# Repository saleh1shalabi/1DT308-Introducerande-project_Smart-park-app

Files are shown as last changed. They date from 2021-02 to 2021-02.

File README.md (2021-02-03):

# team-18

# Smart car counter

## Abstract

Cant see embedded video? Here is the link!
https://youtu.be/MCtellI5bu4

This project aims to provide an better alternate method of keeping track of parking spaces in a parking lot. The current setup is stationary and prone to faults, thus the soulution should be a reliable and portable one. 

A portable device to be placed on each driving lane was developed, making use of a motion detector sensor. The sensor is triggered when a car passes over it and data is sent to an app that presents the live number of available parking spaces. 

## Background and idea
Kalmar kommun asked students at Linneaus university to: Parkeringsplats, fullt eller inte fullt, antal lediga platser. There is a solution right now doing this at many parkingspaces around the city, however there are problems with the current solution. It often show the wrong number of available spaces, and after talking to the contact person at Kalmar kommun, we understand that it requires a subscription or sorts.

Our first idea was to make a stationary solution, but after talkking to the contact at Kalmar kommun, and to our teacher it became clear that a portable sulotion would be more in line with what Kalmar kommun had in mind, and more in scope with the assignment. 

The initial idea was to have two sensors at a distance from eachother, and assume that the one that the car passes first would trigger first. This assumption would then be used to determine the direction of the car. The sensor that was chosen turned out to detect movement in all directions, making it very likely to detect things that are not cars. Taking this in to consideration it was decided that we would instead make a device that is to be placed on the drivinglane so that the cars drive over it. The fact that it now is blocked from below, and is furher from where people are likely to walk will hopefully help with only detecting cars. 

To further help with this the sensor could be shielded on the sides, a resistor can also be added that shortens the sensors range and thus reduce the likelihood of detecting people, birds ect.

Whith the cars driving over the detector, a lazer distance sensor cound probably be used, we didn't consider them with our other ideas because of their typically short range. On the other hand, utilising such a sensor, you could probably be very sure that it only triggers when a car drives over it.

We tried to power it with a 9V battery conected to the sensor, and then power the lopy4 via the sensors 3V3.

To determine the direction of the cars one device is placed on each driving-lane. There is a button on the device that lets you switch between the device laying on a lane where cars drive in to, or out of the parkinglot. Data is then, when the sensor is triggerd, sent to a calculator and middlehand to determine the number of available parking spaces. 

## Method

[Timelog](doc/timelog.md)

[Requirements](doc/requirements.md)

[Hardware](doc/hardware.md)

[Setup](doc/setup.md)

[Test](doc/test.md)

## Results

We succeded with making a program that works as intended with the buttons and the LEDs and the sensor. There is also a 3D printed case for everything and there was an atempt to solder everything together and have it work as a portable unit. we got it to work a few times u it did not work well and was super flimsy. The explanation was probably that we did not have a good solution for powering the device. The lopy4 turned out to need 3.5-5 V in and thus the 3v3 output was to weak. When trying to fix this useing a voltage regulator something went wrong and the lopy4 burned out (sorry) So now our only currently working option is to use a powerbank with USB.

We have a working app that that can display the data, it is also possible to change a few settings such as location as well as reading a little about the product and the members of the team.

Sending and reciving data via LORA and MQTT is still not working as well as we would want and this causes the data in the app and the data sent by the sensor to not agree 100 %.

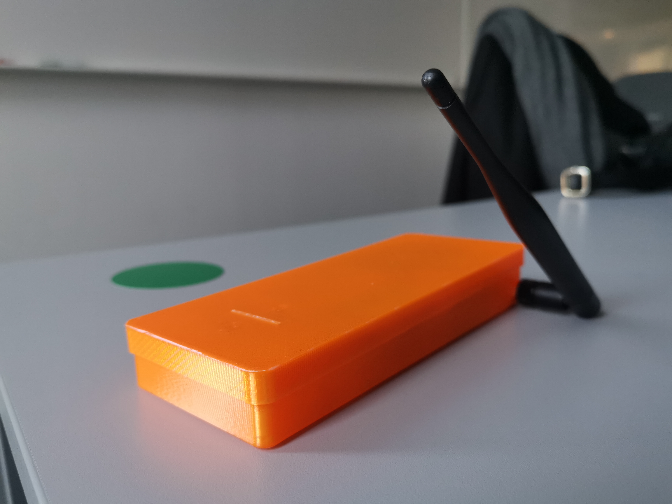
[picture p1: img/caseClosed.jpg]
case

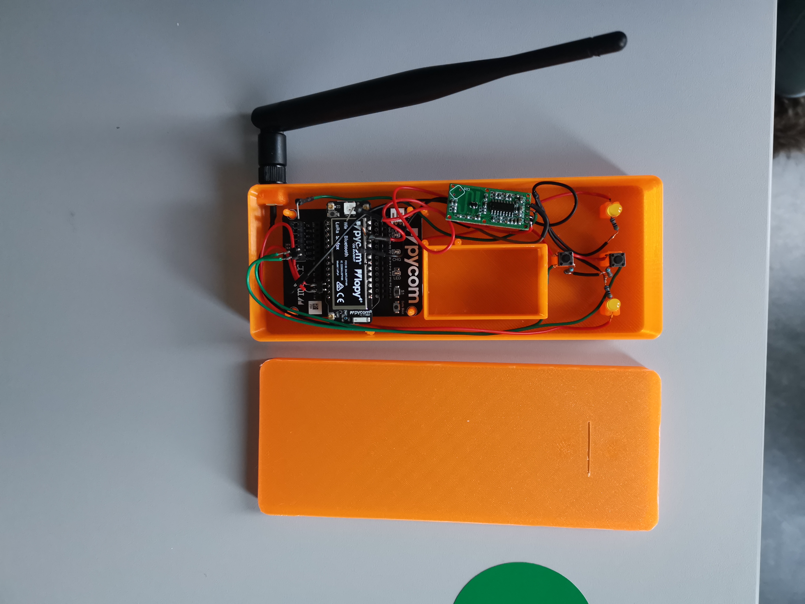
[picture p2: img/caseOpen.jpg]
case inside


## Reflections

### Emelie

Min uppgift var att ta hand om uppkopplingen. Det började med en tanke om att använda TTN för att sedan skicka vidare datan till en MQTT server genom en IFTTT applet. Detta skrotades till sist och ersattes av LoPy to LoPy kommunikation och direkt kommunikation till MQTT-servern via wifi.

Det svåraste med projektet var att komma igång. Vi hängde upp oss på sensorn mer än vi skulle gjort vilket satte stopp för resten av arbetet. Att man är ovan vid grupparbete på distans gjorde inte saken bättre.

Det roligaste var att få hålla på och koppla och testa sig fram för att få sensorn funka (så gott den kunde).

### Saleh

Detta var första gången för mig att programera en app. Det var väldigt utmanande att kunna presentera datan på ett snyggt sätt som det jag kom fram till med i appen, tycker jag åtminstone. Väldigt kul och lärorikt upplevelse.  Eftersom appen behöver få in datan var det lämpligast att programera huvudenheten samtidigt. 

Svårast var det att kunna lära sig flera olika bibliotek på så kort tid. Vissa gånger ville scripten bara inte fungera trötts att det inte fanns något fel i det. Väldigt utmanande att hitta på flera olika sätt att kunna lösa en och samma sak, bara för att ibland ville det inte fungera som man ville.

Jag är väldigt nöjd över det jag fick lära mig under detta projekt, att man fick välja precis det man ville göra var nog det bästa med det då det är mest lärande att man gör något man tycker om! :)

### Elin

Jag var mest ansvarig för vilken logik som skulle användas när sensorn detekterade någonting, att koppla ihop och programmera hårdvaran och att designa ett case till alla delar.

Det svåraste var att släppa att sensorn inte var optimal för ändamålet och den lösning vi hade tänkt först, tillslut blev det någon sorts kompromiss där vi körde på den befintliga sensorn, men försökte anpassa lösningen till hur den funkar.

Det roligaste var att koppla ihop allting och se hur det fungerade tillsammans. Det var kul att lära sig mer om att arbeta i 3D, och det var kul att löda ihop allting, även om något gick fel så att det inte funkade på slutet.

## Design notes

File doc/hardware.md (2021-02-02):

# Hardware and hardware setup 

* LoPy 4
* Antenna
* RCWL-5016
* 9 V powersource
* 2 Leds
* 2 buttons
* 2 1K ohm pulldownresistor

## Explanations

The two leds will be used to indicate if the device is meant to be placed on the in-lane or on the out-lane. The device is placed in the middle of the drivinglane, its range is hopefully short enough so that something detected can be assumed to be a car driving on the in-lane --> +1 car on the parkinglot. One of the buttons is to swich between these two modes. The other button is to start and stop the process of detecting cars and sending data.The sensor has a 360 degree detection range radar that sends out microwaves and measures potential differenses in the returning wavelengths to determine movement. 

## Setup

koppligsschema

Each component is connected with cables here represented by "<-->".

#### OUT-LED
* LoPy4 P12 <--> LED <--> resistor <--> LoPy4 GND

#### IN-LED
* LoPy4 P11 <--> LED <--> resistor <--> LoPy4 GND

#### Start/stop button
* LoPy4 P9 <--> Button <--> resistor <--> LoPy4 GND
* Button <--> LoPy4 3V3

#### Button switch
* LoPy4 P8 <--> Button <--> resistor <--> LoPy4 GND
* Button <--> LoPy4 3V3

#### RCWL-5016
* LoPy4 VIN(can be used as 5V powersource) <--> RCWL-5016 VIN
* RCWL-5016 output <--> LoPy4 P6
* RCWL-5016 GND <--> LoPy4 GND

#### Antenna
* Directly connected to either of LoPy4's LoRa antennas.

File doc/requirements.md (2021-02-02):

# Car counter

## Problem
Kalmar kommun has specified the following problem: Parkeringsplats, fullt eller inte fullt, antal lediga platser.

* People park for to long or without paying.
* The current way to count available parkingspaces does not work well.

___
## User stories
* *US1*: As a user I must be able to access information about how many cars has entered and exited the parkinglot since the device was placed.
* *US2*: As a user I could be able to enter the number of cars that are already on the parkinglot.
* *US3*: As a user I could be able to enter the total number of parkingspaces on the parkinglot.
* *US4*: As a user I could be able to see how many free spaces there are on a certain parkinglot.
___
## Device requierments

* *DR1*: The device must be portable and easy to set up.
* *DR2*: The device must be a selfcontained unit.
* *DR3*: The device must try to utilize the available sensors.
* *DR4*: The device must be safe to place.
* *DR5*: The device could use a magnetic sensor to further verify that is is a car and not something else.
---
## Breakdowns

### **User story breakdowns**

* **US1**
    * US11: When the device detects a car this information is saved and sent to a server.
    * US12: By subscribing to this server you can access the information about the number of cars that have entered or exited the parkinglot.

* **US2**
    * US21: The case of the device have buttons that make it possible to enter numbers.
    * US22: The case of the device has a little screen that ask the user to enter the number of cars. 
    * US23: The screen can show what number have been entered.
    * US24: The case of the device have an 'OK' or 'Enter' button wich the user can press to finish writing in the number.
    * US25: The entered number is sent to the server.

* **US3**
    * US31: See US21
    * US32: See US22
    * US33: See US23
    * US34: See US24
    * US35: See US25

* **US4**
    * US41: When the server recives in formation about the number of spaces it subtracts used spaces from total spaces.
    * US42: Each time a car exits or enters the available space change.

### **Device requirement breakdowns**

* **DR1**
    * DR11: The device must be relativley easy to move and carry.
    * DR12: A user should be able to carry the device in one hand.
    * Placing the device should be as simple as laying it on the ground or atatching it to a dedicated mount.

* **DR2**
    * DR21: A case should be designed that contains everything the device needs.
        * lopy 4
        * battery
        * Lora antenna
        * Sensors 
        * screen (if time permitts)
        * Buttons (if time permitts)
        * coil (if time permitts)
    
    * DR22: The case is designed to be 3D-printed.

* **DR3**
    * DR31: Different ways of utilising the RCWL-0516.
        * One device for each lane
        * Each time the sensor gives a signal it is counted as a car.
        * The direction of the car is determined based on wich lane the device is placed on.
    * DR32: Problems with the RCWL-0516.
        * The sensor 'looks' in all directions, so it will detect cars in other places than the lane it is placed on.
        * The sensor reacts to pedestrians.
        * The sensor seams unreliable. 
    * DR33: The sensor could be screened of to help with some of the problems.

    * DR34: Designing the device to be placed on the lane with the sensor facing uppwards could help with some of the problems.
        * Cars drive over the cevice.
        * Device must be flat and low to the ground.
        * Device must be highley vissible.
    * Adding the resistor that limits the sensors range from 7 meters to 5 meters could help with some of the problems.

* **DR4**
    * DR41: Placing the device must not involve spending unnescesery time on or in conection to the road.
    * DR42: While placing the device the user must be able to be highly vissible.
    * DR43: While placing the device the user must be able to keep their attention on their suroundings. 

* **DR5**
    * DR51: Different magnetic sensors that could be used:
        * digital hall sensor.
        * A coil (placed iside, around the edges of a round case)
    * DR52: When the RCWL-0516 sences something the magnetic sensor verifies that it is likely a car and not a pedestrian.

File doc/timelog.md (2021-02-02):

# Timelog

|Date | Activity | Time
|:-:|:-|:-:|
| 2/12 | Alla träffades för att planera parkering mm. | 45-60 min |
| 3/12 | Alla hade möte med Simon Vestlund ang projektet. | 20 min |
|| Gruppmedlemmarna hade samtal efter mötet | 15 min |
| 8/12 | Emelie jobbade med conencting. | 2h |
|| Saleh arbetade med lora, förståelse om pycom kontakten enhet till enhet via lora, kollade alt. om en Mqtt broker/server skulle skapas på egen hand. | 3h |
| 10/12 | Alla har möte med Fredrik.| 20 min |
|| Alla hade ett litet möte | 20 min |
|| Alla försöker bestämma sig för sensortyp mm. |  5h  |
|| Saleh läste om webserverar | 2h |
|| Saleh fortsatte kolla med appen | 1h |
| 11/12 | Saleh kollade hur man skapar en mobil app, läste om kivy och kivymd, kollade buldozer som pressar program filerna till mobil app. | 6h|
| 16/12 | Alla experimenterar med sensor och pratar i Discord | 5h |
|| Saleh fortsatte kolla med appen | 1h|
| 17/12 | Emelie och Saleh möte med Fredrik. | 15 min |
|| Alla samtal | 30 min |
|| Emelie jobbade med connection. | 2h |
|| Saleh test skapa enkla appar för att ha djupare förståelse till det | 5h |
| 18/12 | Emelie fixade IDE/pymakr som gett upp. | 3h |
|| Saleh mer om mobilappar och kollade sensorn med test köra lite kod med den för att få den att funka. | 3h |
| 4/1 | Alla hade planeringsmöte. | 3h |
|| Saleh kollade alt sensor | 1.5h |
| 6/1 | Emelie försökte få uppkoppling att funka.| 3h |
| 7/1 | Elin börjar skriva kravspec | 1 tim |
|| Emelie fortsatte med uppkoppling och även gateway. | 2h|
||  Alla hade möte om hur vi ska gå tillväga. | 2h |
| 8/1 | Emelie löste uppkoppling (äntligen). | 3h |
| 9/1 | Emelie kopplade TTN till io.adafruit.| 40min |
| 10/1 | Elin skriver requirement breakdowns | 2.5h |
||  Saleh app designen, kollade med ttn kopplingen och lora | 4h |
|| Elin gör det möjligt att välja vilket läge enheten är i | 3 tim |
|| Alla har samtal | 30 min |
|11/1| Elin jobbar med prototyp. lägger till startknapp och sensor | 4 tim |
|| Elin ritar kopplingsschema för prototyp | 30 min |
||Elin jobbar med delivarables | 2 tim |
|| Saleh Jobbar med mqtt uppkoppling och appen | 5h |
|12/1| Elin designar case | 8 tim |
|13/1| Elin kopplar och löder ihop allting för att passa i caset|5 tim|
|14/1| Alla jobbade med det sista med conenction och hardware | 8h |
|| Alla hade möte | 2h |
|| Saleh fixade med appen | 5h |
|15/1| Alla jobbar med finslip, hardware-strul och film | 10h |

## Diagram

Blue - Saleh
Red - Emelie
Yellow - Elin
Green - All

case

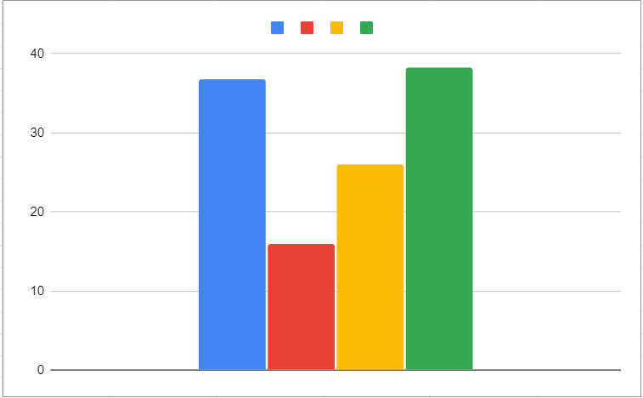
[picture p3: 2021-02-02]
img/time.PNG

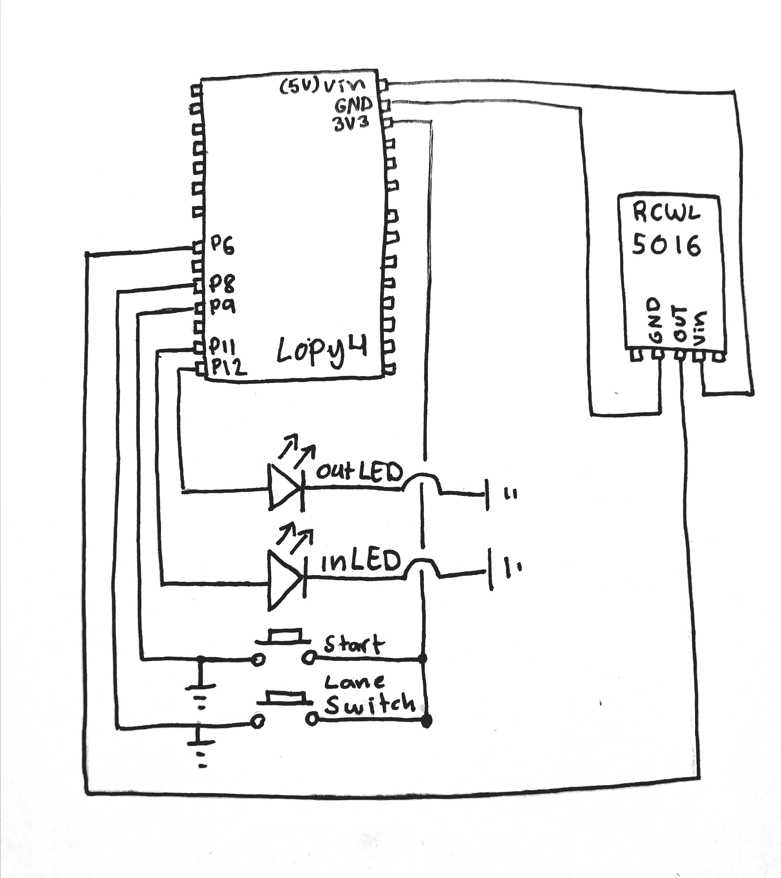
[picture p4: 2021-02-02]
img/Kopplingsschema.jpg

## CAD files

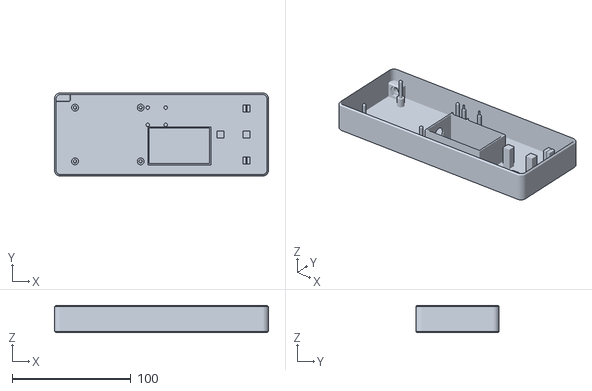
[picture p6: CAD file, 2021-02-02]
img/case/case.stl
180.0 x 70.0 x 23.0

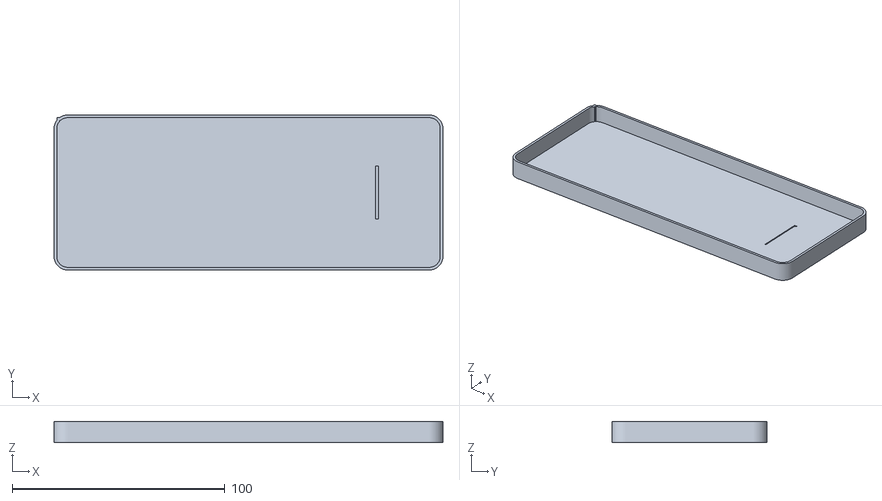
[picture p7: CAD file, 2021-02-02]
img/case/lid.stl
183.0 x 73.0 x 10.0

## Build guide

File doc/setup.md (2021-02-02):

# Setup

## Components

* io.adafruit
    * feed - recieves data from main_device_code
* car_counter
    * main.py - buttons and LED's controlls, sends message to main device when sensor is triggerd, either Car_IN or Car_OUT
    * boot.py - connect to lora
* main_device_code
    * main.py - recives data from car_counter, uploads data to MQTT server, calculates the net sum of passing cars, conencts to lora, wifi and MQTT
    * boot.py - 
    * lib -  
* app
    * main.py - create the graphical interface the presents the collected data
    * connect.py - connects to MQTT

## Setup

### io.adafruit

The only setup needed is to change the authentications for the MQTT server and wifi. 

### car_counter

You might need to change the pin numbers to correspond with the pins you chose when setting up your hardware. If bouncing is going crazy you could try to adjust the variable "bounceTime". You can also adjust how the LEDs behave. Look for this part in the code: 

```{python}

#----------------------------------------------------------------------
#Variables you might want to adjust

bounceTime = 100 # how much time must pass when checking for button bounce

#LIGHTS
blinkRepeat = 3 # how many times the lights will blink when the device starts or stops counting cars.
blinkTimeON = 0.2 # how long time the lights will be on when blinking
blinkTimeOFF = 0.5 # how long the lights will be off when blinking
timeON = 1 # how long the light will be on when indicating a switch
#-------------------------------------------------------------------------
```

### main_device_code

Authentications for wifi connection will need to be changed to the proper one.

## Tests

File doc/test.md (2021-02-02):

# Test

Take a lopy device and run the car_counter code. Press the 'switch' button: one of the LEDs should light up for a second to indicate witch mode is chosen, when the button is pressed again the other LED should light up. Press the buttons a few times and look at the terminal to see if there is bouncing. if the led changes again directly after a press the softwhere didnt succesfully identify a bounde. choose one LED. Press the start button, the chosen LED should blink three times. Set up a MQTT server with a feed to subscribe to. Now take another lopy and run the "main_device_code" code and alter authentication as needed, the MQTT should display a number that alter when the sensor is triggerd. Either adding or subtracting depending on the chosen LED. Test for both LED's. Look in the terminal of car_counter and see if it prints 'car going in' and 'car going out accordinly'.

When you run the main_device_code you can look in the terminal at the messages it is recieving. When the 'in-lane-mode' is chosen the message should be 'Car_IN', when the out-lane LED is chosen the message should be 'Car_OUT'. If you want to check witch mode is the current one, press the start button again and the LED corresponding to the current mode should blink three times. A message is sent each time the sensor detects movement. If you press the switch button the other led should blink three times and the message should change. When you want to stop sending messages and lisstening to the sensor hold the start button for about 10 seconds when both lights light up it means the car counting has stopped. if one LED blinks when you press the button, or after both leds lit up it is because of bouncing. Try holding the button again.

Tip!
If you want to have more control of when a message is sent, for testing, you could change the sensor for another button. Connect in the same manner as the other buttons.

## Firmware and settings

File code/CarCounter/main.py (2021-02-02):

from machine import Pin
import time
import utime
import _thread
import socket
import struct
import pycom

#boolians to let me check what is going on at a given moment.
inLane = True
justStopped=False
blinking = False

s = socket.socket(socket.AF_LORA, socket.SOCK_RAW)
s.setblocking(False)

#timestamps to check bouncing. Tame for car is needed when testing with a button
#instead of a sensor.
timeForLastSwitch = utime.ticks_ms()
timeForStartButton = utime.ticks_ms()
timeForCar = utime.ticks_ms()

inLaneLed = Pin('P11', mode=Pin.OUT)
outLaneLed = Pin('P12', mode=Pin.OUT)

startButton = Pin('P9',mode=Pin.IN, pull=None)
laneSwitchButton = Pin('P8', mode= Pin.IN, pull=None)
motionSensor = Pin('P6', mode=Pin.IN)
#----------------------------------------------------------------------
#Variables you might want to adjust

bounceTime = 100 # how much time must pass when checking for button bounce

#LIGHTS
blinkRepeat = 3 # how many times the lights will blink when the device starts or stops counting cars.
blinkTimeON = 0.2 # how long time the lights will be on when blinking
blinkTimeOFF = 0.5 # how long the lights will be off when blinking
timeON = 1 # how long the light will be on when indicating a switch

#-------------------------------------------------------------------------

print('starting')

#this function is called when the 'switch' button is pressed.
def laneSwitch(argument):

    global inLane
    global timeForLastSwitch
    global inLaneLed
    global outLaneLed
    global timeON


    if bounceCheck(timeForLastSwitch):
        return

    if inLane:
        inLaneLed.value(0)
        outLaneLed.value(1)
        print('I just swiched from in lane to out lane!')

    else:
        inLaneLed.value(1)
        outLaneLed.value(0)
        print('I just swiched from out lane to in lane!')
    time.sleep(timeON)
    inLaneLed.value(0)
    outLaneLed.value(0)
    inLane = not inLane
    timeForLastSwitch = utime.ticks_ms()

def startFunction(argument):

    global startButton
    global timeForStartButton
    global justStopped

    if bounceCheck(timeForStartButton):
        return

    timeForStartButton = utime.ticks_ms()

    #we will stop by holding in the start button. when we let it go, this will
    #trigger a new startFunction, unless we make it so we can check if we just
    #stopped.
    if justStopped:
        justStopped = False
        return

    startButton.callback(Pin.IRQ_FALLING, None)

    print('starting')
    _thread.start_new_thread(mainCarCountingFunction, ())
    _thread.start_new_thread(blinkLightsXTimes, ())


def stopFunction(argument):

    global startButton
    global timeForStartButton
    global motionSensor
    global justStopped
    #
    # if time.ticks_diff(utime.ticks_ms(), timeForStartButton) < 100:
    #     print('to soon probably a bounce')
    #     return
    print('stopFunction')
    timeForStartButton = utime.ticks_ms()

    #will stop the car counting if start button is held for five seconds.
    while startButton.value() == 1:

        if utime.ticks_diff(utime.ticks_ms(), timeForStartButton) > 5000:
            print('no more car')
            motionSensor.callback(Pin.IRQ_RISING, None)
            timeForStartButton = utime.ticks_ms()
            bothLights()
            startButton.callback(Pin.IRQ_FALLING, startFunction)
            justStopped=True

            return
    blinkLightsXTimes()



def mainCarCountingFunction():
    global motionSensor
    global startButton
    global timeForStartButton

    time.sleep(3)
    print('entering a loop')
    motionSensor.callback(Pin.IRQ_RISING, carDetected)
    startButton.callback(Pin.IRQ_RISING, stopFunction)


def carDetected(argument):
    global timeForCar

    #needed when using a button while testing
    if bounceCheck(timeForCar):
        return

    timeForCar = utime.ticks_ms()

    if inLane:
        print('Car detected going in')
        s.send('Car_IN')
    else:
        print('Car detected going out')
        s.send('Car_OUT')

#blinks light ineffinetley, battery draining
def blinkLights():
    global blinking
    global outLaneLed
    global inLaneLed

    blinking = True
    while blinking:
        if inLane:
            blinkThisLight(inLaneLed)
        else:
            blinkThisLight(outLaneLed)

def blinkLightsXTimes():
        global blinkRepeat
        global outLaneLed
        global inLaneLed


        for _ in range(blinkRepeat):
            if inLane:
                blinkThisLight(inLaneLed)
            else:
                blinkThisLight(outLaneLed)


def blinkThisLight(light):

        global blinkTimeON
        global blinkTimeOFF

        light.value(1)
        time.sleep(blinkTimeON)
        light.value(0)
        time.sleep(blinkTimeOFF)

def stopBlinking():
    global blinking
    blinking = False

def bothLights():
    global inLaneLed
    global outLaneLed
    global timeON

    inLaneLed.value(1)
    outLaneLed.value(1)
    time.sleep(timeON)
    inLaneLed.value(0)
    outLaneLed.value(0)

def bounceCheck(timeStamp):

    global bounceTime

    if time.ticks_diff(utime.ticks_ms(), timeForLastSwitch) < bounceTime:
        print('to soon probably a bounce')
        return True
    return False


print('after functions')


laneSwitchButton.callback(Pin.IRQ_FALLING, laneSwitch)
startButton.callback(Pin.IRQ_FALLING, startFunction)

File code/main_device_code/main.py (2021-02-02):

import machine
import pycom
from network import LoRa
from network import WLAN
import socket
import time

from mqtt import MQTTClient


# lora to lora connect
lora = LoRa(mode=LoRa.LORA, region=LoRa.EU868)

s = socket.socket(socket.AF_LORA, socket.SOCK_RAW)
s.setblocking(False)

time.sleep(2)




Cars_TOT = 0            # parked cars defult value
Places = 50             # availble places defult value
car_count = 0           # checker




wlan = WLAN(mode=WLAN.STA)

def wifi_connect():
    # connect to wifi
    wlan = WLAN(mode=WLAN.STA)
    wlan.connect("LNU-iot", auth=(WLAN.WPA2, "modermodemet"), timeout=5000)

    while not wlan.isconnected():
        machine.idle()
    print("Connected to WiFi\n")



wifi_connect()




def sub_cb(topic, msg):
    global Cars_TOT, Places, car_count

    if msg == b"update": # when msg "update" publish values
        client.publish(topic="saleh_shalabi/feeds/Cars_TOT", msg=str(Cars_TOT))
        client.publish(topic="saleh_shalabi/feeds/Places", msg=str(Places))
    if topic == b"saleh_shalabi/feeds/reset_Cars":  # when msg gotten on reset car topic changes the values
        Cars_TOT = int(msg.decode("utf-8"))
        car_count = Cars_TOT

    if topic == b"saleh_shalabi/feeds/reset_Plac": # when msg gotten on reset places values
        Places = int(msg.decode("utf-8"))

    return Cars_TOT, Places, car_count







client = MQTTClient("lopy-saleh", "io.adafruit.com",user="saleh_shalabi", password="aio_eTQR01nk0h3dknsfy28Y37iWfW7c", port=1883)


client.set_callback(sub_cb)

client.connect()
client.subscribe(topic="saleh_shalabi/feeds/App")
client.subscribe(topic="saleh_shalabi/feeds/reset_Plac")
client.subscribe(topic="saleh_shalabi/feeds/reset_Cars")



print("mqtt connected")

while True:
    try:
        while not wlan.isconnected(): # if connection lost
            wifi_connect() # reconnect to wifi
            # re connect to mqtt server

            client.connect()
            client.subscribe(topic="saleh_shalabi/feeds/App")
            client.subscribe(topic="saleh_shalabi/feeds/reset_Plac")
            client.subscribe(topic="saleh_shalabi/feeds/reset_Cars")
            print("Conncetion lost, but istablished agane")
        else:
            client.check_msg() # check msg on mqtt


            if s.recv(64) == b'Car_IN':  # if a msg by lora from a device and its "Car_IN"
                print(s.recv(64))
                if Places == 0:         # check the values
                    print("where Are u going to park")
                else:                   # new values if there is places
                    Cars_TOT = Cars_TOT + 1
                    Places = Places - 1

            if s.recv(64) == b'Car_OUT':    #   if a msg by lora from a device and its "Car_OUT"
                print(s.recv(64))
                if Cars_TOT == 0:               # check values
                    print("how did this car even got in")
                else:                               # new values
                    Cars_TOT = Cars_TOT - 1
                    Places = Places + 1

            # check new values and publish it
            if Cars_TOT == (car_count +1):
                print("Cars + 1")
                client.publish(topic="saleh_shalabi/feeds/Cars_TOT", msg=str(Cars_TOT))
                client.publish(topic="saleh_shalabi/feeds/Places", msg=str(Places))
                car_count = car_count +1

            elif Cars_TOT == (car_count - 1):
                print("Cars - 1")
                client.publish(topic="saleh_shalabi/feeds/Cars_TOT", msg=str(Cars_TOT))
                client.publish(topic="saleh_shalabi/feeds/Places", msg=str(Places))
                car_count = car_count - 1

    except Exception as e:
        print(e)
